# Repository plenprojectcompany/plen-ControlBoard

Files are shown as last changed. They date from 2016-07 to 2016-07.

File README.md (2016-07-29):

PLEN2 ControlBoard | PLEN Project Company
===============================================================================

## Copyright (c) 2015,
- [Naohiro HAYAISHI](http://earlystone.com/)
- [Mitsuhiro MIYAGUCHI](https://github.com/mitsuhiromiyaguchi)
- [PLEN Project Company Inc.](https://plen.jp)

## Build Environment
- Windows 8.1
- Eagle 6.60

## License
This material is released under the Creative Commons BY 4.0.

**Attention!**  
The schematic diagram of Arduino Micro in schematic file is licensed by Arduino. Please see the detail on their [web-site](https://www.arduino.cc/).
The schematic diagram of Multi-ServoMotor Interface, RS485 communication port and EEPROM is released under Creative Commons Attribution 4.0 International Public License.

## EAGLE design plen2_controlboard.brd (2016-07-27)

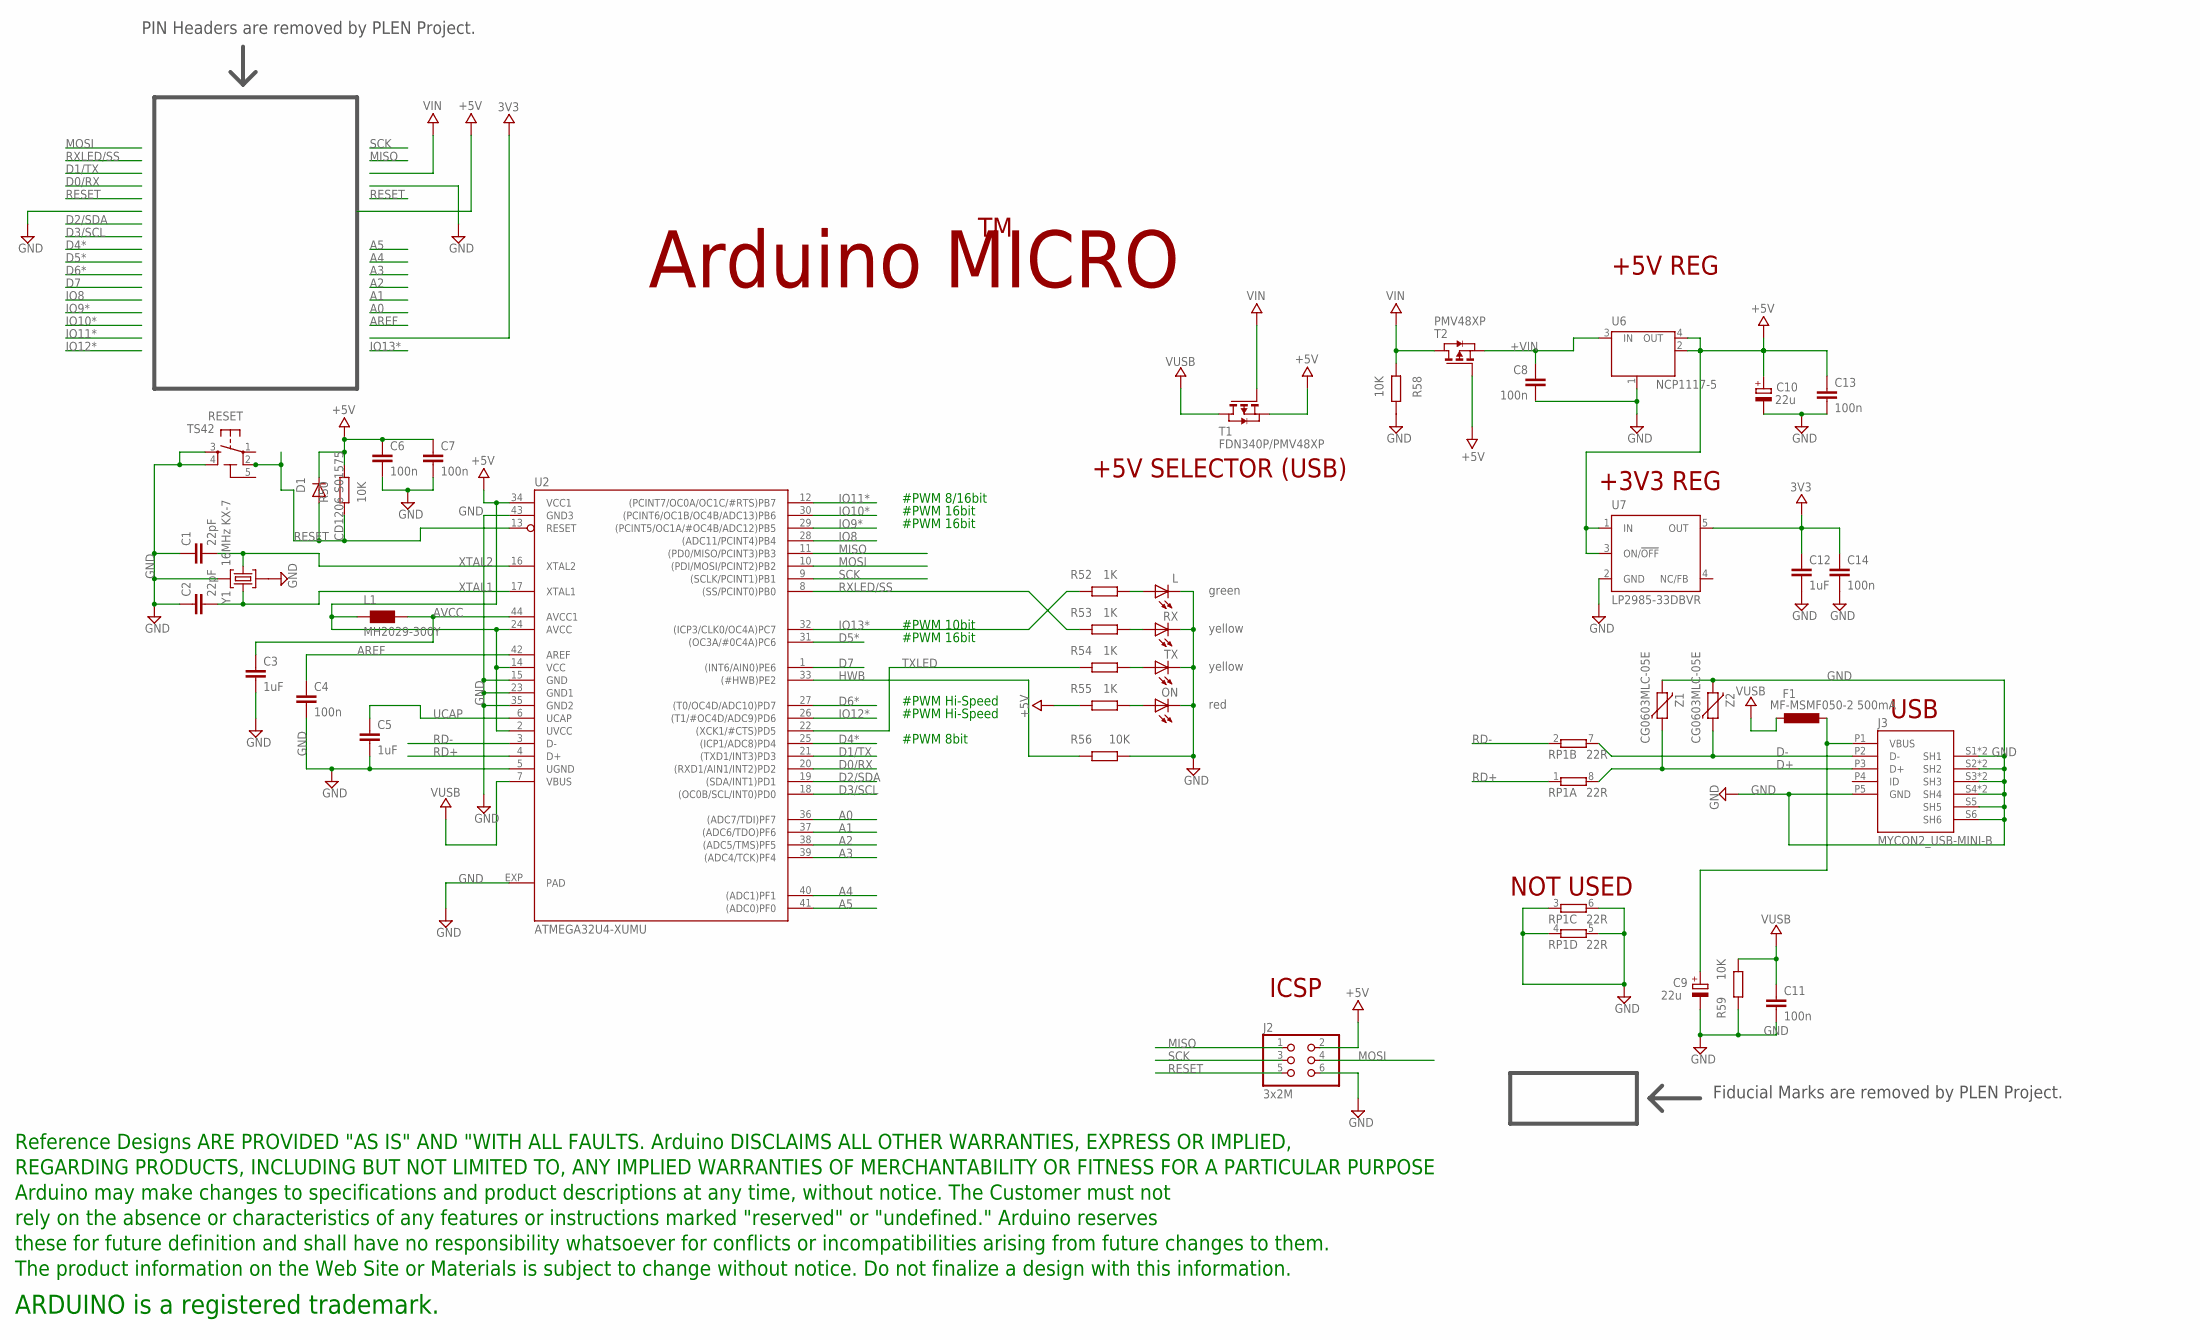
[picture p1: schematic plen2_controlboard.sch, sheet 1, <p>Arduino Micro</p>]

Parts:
C1, C2: 22pF; C0402
C3, C5, C12: 1uF; C0402
C4, C6, C7, C8, C11, C13, C14: 100n; C0402
C9, C10: 22u; SMC_B
D1: CD1206-S01575; MINIMELF
F1: MF-MSMF050-2 500mA; L1812
J2: 3x2M; 2X03
J3: MYCON2_USB-MINI-B; CON2_USB_MICRO_B_AT
L: green; CHIPLED_0805
L1: MH2029-300Y; 0805
ON: red; CHIPLED_0805
R50, R56, R58, R59: 10K; R0402
R52, R53, R54, R55: 1K; R0402
RESET: TS42
RP1: 22R; CAY16
RX: yellow; CHIPLED_0805
T1: FDN340P/PMV48XP; SOT-23
T2: PMV48XP; SOT-23
TX: yellow; CHIPLED_0805
U2: ATMEGA32U4-XUMU; QFN44ML7X7
U6: NCP1117-5; LINEAR_SOT223
U7: LP2985-33DBVR; SOT23-DBV
U$3: DISCLAIMER
Y1: 16MHz KX-7; CRYSTAL-3.2-2.5
Z1, Z2: CG0603MLC-05E; CT/CN0603

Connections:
3V3: C12.1, C14.1, U7.5 (OUT); also elsewhere on the board
5-GND: RESET.5 (5-GND)
+5V: C6.1, C7.1, C10.+, C13.1, D1.C, J2.2, L1.1, R50.1, R55.1, T1.2 (S), T2.3 (G), U2.2 (UVCC), U2.14 (VCC), U2.24 (AVCC), U2.34 (VCC1), U6.2 (OUT), U6.4 (OUT), U7.1 (IN), U7.3 (ON/!OFF); also elsewhere on the board
+VIN: C8.1, T2.2 (S), U6.3 (IN)
A0: U2.36 ((ADC7/TDI)PF7)
A1: U2.37 ((ADC6/TDO)PF6)
A2: U2.38 ((ADC5/TMS)PF5)
A3: U2.39 ((ADC4/TCK)PF4)
A4: U2.40 ((ADC1)PF1)
A5: U2.41 ((ADC0)PF0)
AREF: C4.1, U2.42 (AREF)
AVCC: C3.1, L1.2, U2.44 (AVCC1)
D0/RX: U2.20 ((RXD1/AIN1/INT2)PD2); also elsewhere on the board
D1/TX: U2.21 ((TXD1/INT3)PD3); also elsewhere on the board
D2/SDA: U2.19 ((SDA/INT1)PD1); also elsewhere on the board
D3/SCL: U2.18 ((OC0B/SCL/INT0)PD0); also elsewhere on the board
D4*: U2.25 ((ICP1/ADC8)PD4); also elsewhere on the board
D5*: U2.31 ((OC3A/#0C4A)PC6); also elsewhere on the board
D6*: U2.27 ((T0/OC4D/ADC10)PD7); also elsewhere on the board
D7: U2.1 ((INT6/AIN0)PE6)
D+: J3.P3 (D+), RP1.8 (2), Z1.1
D-: J3.P2 (D-), RP1.7 (2), Z2.1
GND: C1.1, C2.1, C3.2, C4.2, C5.2, C6.2, C7.2, C8.2, C9.-, C10.-, C11.2, C12.2, C13.2, C14.2, J2.6, J3.P5 (GND), J3.S1 (SH1), J3.S2 (SH2), J3.S3 (SH3), J3.S4 (SH4), J3.S5 (SH5), J3.S6 (SH6), J3.S7 (SH1), J3.S8 (SH2), J3.S9 (SH3), J3.S10 (SH4), L.C, ON.C, R56.2, R58.1, R59.1, RESET.3, RESET.4, RP1.3 (1), RP1.4 (1), RP1.5 (2), RP1.6 (2), RX.C, TX.C, U2.5 (UGND), U2.15 (GND), U2.23 (GND1), U2.35 (GND2), U2.43 (GND3), U2.EXP (PAD), U6.1 (GND/ADJ), U7.2 (GND), Y1.2 (GND), Y1.4 (GND), Z1.2, Z2.2; also elsewhere on the board
HWB: R56.1, U2.33 ((#HWB)PE2)
IO8: U2.28 ((ADC11/PCINT4)PB4)
IO9*: U2.29 ((PCINT5/OC1A/#OC4B/ADC12)PB5); also elsewhere on the board
IO10*: U2.30 ((PCINT6/OC1B/OC4B/ADC13)PB6); also elsewhere on the board
IO11*: U2.12 ((PCINT7/OC0A/OC1C/#RTS)PB7); also elsewhere on the board
IO12*: U2.26 ((T1/#OC4D/ADC9)PD6); also elsewhere on the board
IO13*: R52.1, U2.32 ((ICP3/CLK0/OC4A)PC7)
MISO: J2.1, U2.11 ((PD0/MISO/PCINT3)PB3)
MOSI: J2.4, U2.10 ((PDI/MOSI/PCINT2)PB2)
unnamed: R53.2, RX.A
unnamed: ON.A, R55.2
unnamed: R54.2, TX.A
unnamed: L.A, R52.2
RD+: RP1.1, U2.4 (D+)
RD-: RP1.2 (1), U2.3 (D-)
RESET: D1.A, J2.5, R50.2, RESET.2, U2.13 (RESET); also elsewhere on the board
RXLED/SS: R53.1, U2.8 ((SS/PCINT0)PB0)
SCK: J2.3, U2.9 ((SCLK/PCINT1)PB1)
TXLED: R54.1, U2.22 ((XCK1/#CTS)PD5)
UCAP: C5.1, U2.6 (UCAP)
VIN: R58.2, T1.3 (G), T2.1 (D); also elsewhere on the board
VUSB: C11.1, F1.2, R59.2, T1.1 (D), U2.7 (VBUS)
VUSBD: C9.+, F1.1, J3.P1 (VBUS)
XTAL1: C2.2, U2.17 (XTAL1), Y1.3 (C2)
XTAL2: C1.2, U2.16 (XTAL2), Y1.1 (C1)

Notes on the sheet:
Arduino MICRO
+5V REG
ICSP
USB
+5V SELECTOR (USB)
NOT USED
+3V3 REG
#PWM 8bit
#PWM Hi-Speed
#PWM 16bit
#PWM 10bit
#PWM 8/16bit
Fiducial Marks are removed by PLEN Project.
PIN Headers are removed by PLEN Project.

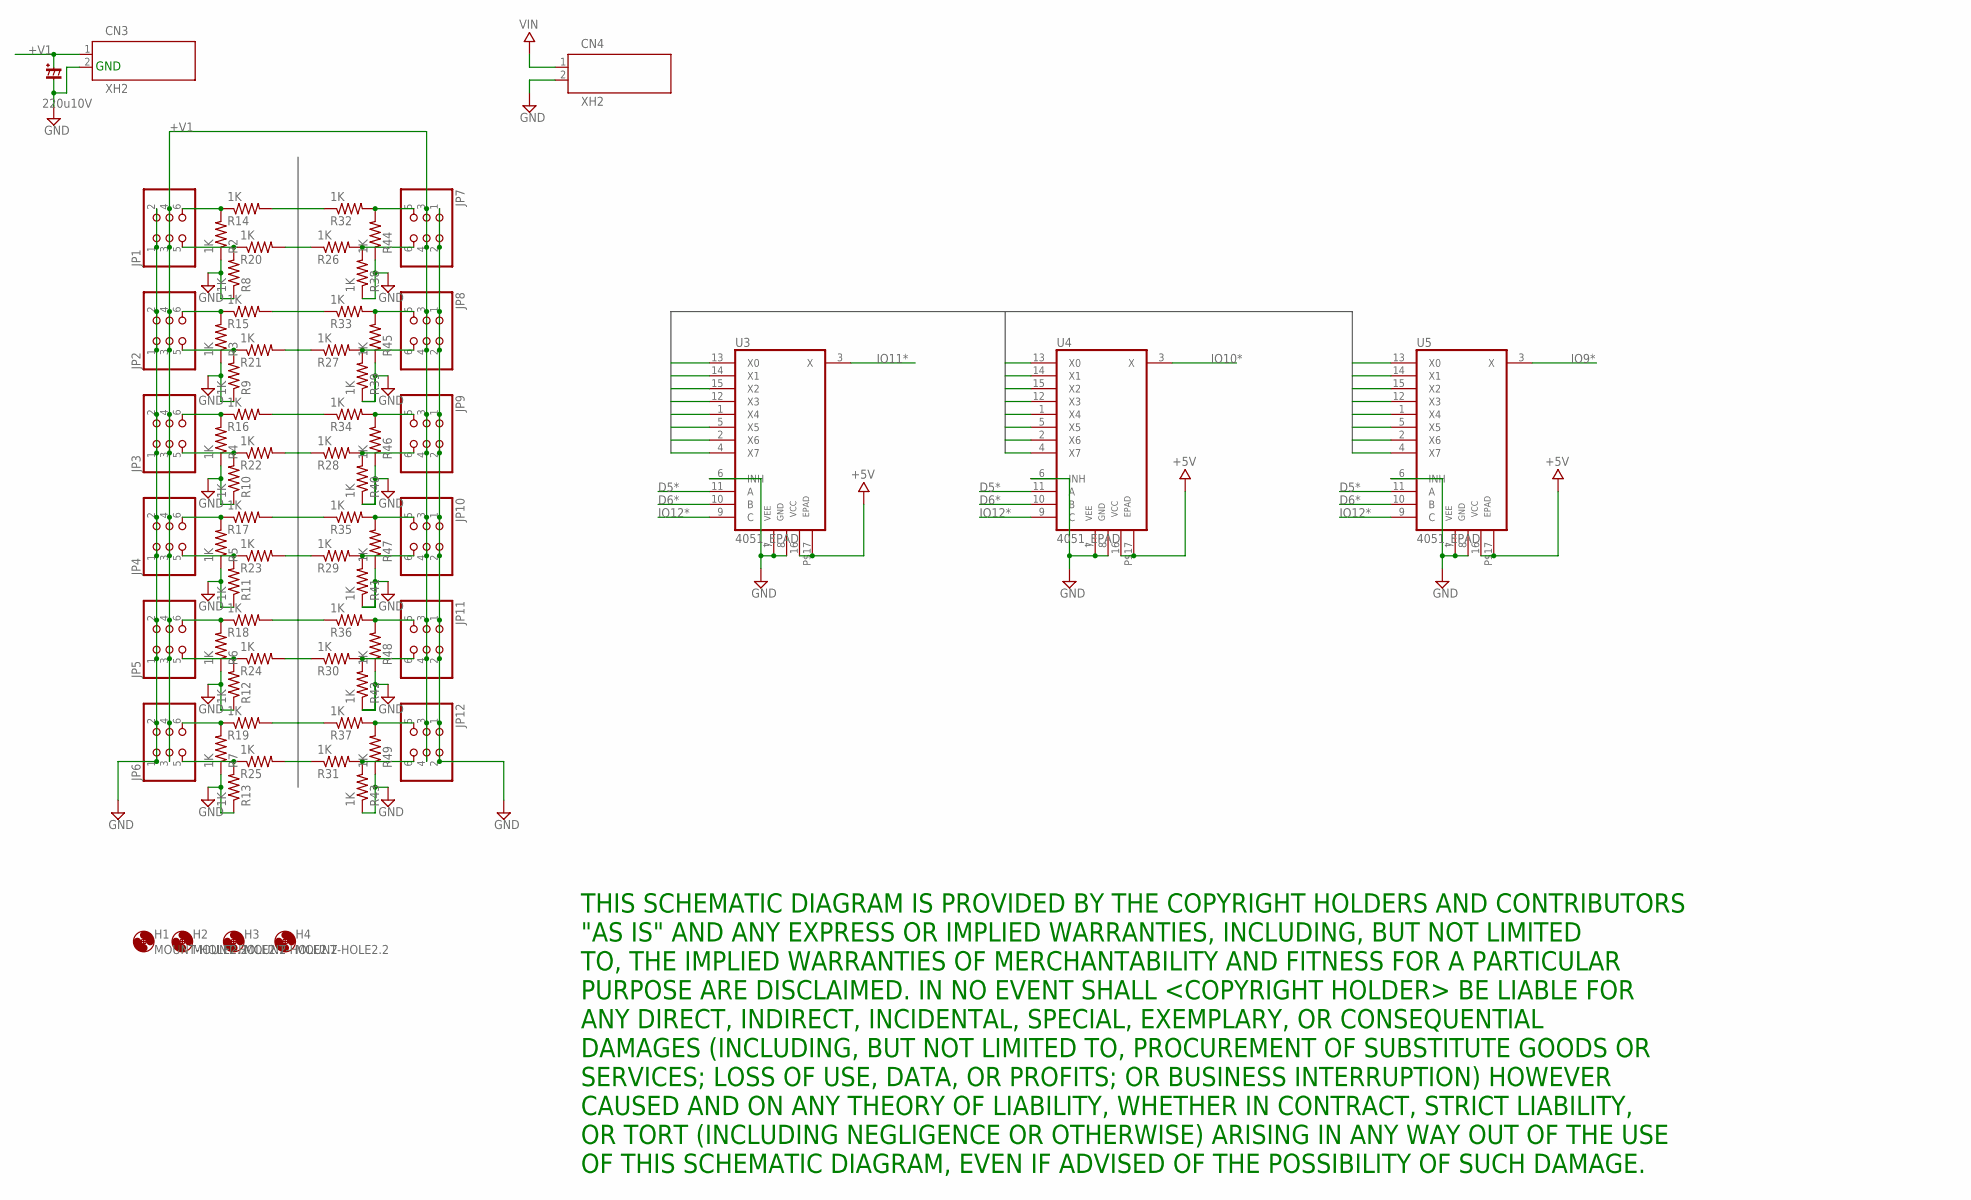
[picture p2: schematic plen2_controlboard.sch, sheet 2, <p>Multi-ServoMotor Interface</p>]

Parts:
CN3, CN4: XH2
CP1: 220u10V; CP_S05-05
H1, H2, H3, H4: MOUNT-HOLE2.2; 2,2
JP1, JP2, JP3, JP4, JP5, JP6, JP7, JP8, JP9, JP10, JP11, JP12: PINHD-2X03_2.54; 2X03
R2, R3, R4, R5, R6, R7, R8, R9, R10, R11, R12, R13, R14, R15, R16, R17, R18, R19, R20, R21, R22, R23, R24, R25, R26, R27, R28, R29, R30, R31, R32, R33, R34, R35, R36, R37, R38, R39, R40, R41, R42, R43, R44, R45, R46, R47, R48, R49: 1K; R0402S
U3, U4, U5: 4051_EPAD; SOT763-1

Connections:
+5V: U3.16 (VCC), U3.P$17 (EPAD), U4.16 (VCC), U4.P$17 (EPAD), U5.16 (VCC), U5.P$17 (EPAD); also elsewhere on the board
+V1: CN3.1, CP1.+ (1), JP1.3, JP1.4, JP2.3, JP2.4, JP3.3, JP3.4, JP4.3, JP4.4, JP5.3, JP5.4, JP6.3, JP6.4, JP7.3, JP7.4, JP8.3, JP8.4, JP9.3, JP9.4, JP10.3, JP10.4, JP11.3, JP11.4, JP12.3, JP12.4
D5*: U3.11 (A), U4.11 (A), U5.11 (A); also elsewhere on the board
D6*: U3.10 (B), U4.10 (B), U5.10 (B); also elsewhere on the board
GND: CN3.2, CN4.2, CP1.- (2), JP1.1, JP1.2, JP2.1, JP2.2, JP3.1, JP3.2, JP4.1, JP4.2, JP5.1, JP5.2, JP6.1, JP6.2, JP7.1, JP7.2, JP8.1, JP8.2, JP9.1, JP9.2, JP10.1, JP10.2, JP11.1, JP11.2, JP12.1, JP12.2, R2.1, R3.1, R4.1, R5.1, R6.1, R7.1, R8.1, R9.1, R10.1, R11.1, R12.1, R13.1, R38.1, R39.1, R40.1, R41.1, R42.1, R43.1, R44.1, R45.1, R46.1, R47.1, R48.1, R49.1, U3.6 (INH), U3.7 (VEE), U3.8 (GND), U4.6 (INH), U4.7 (VEE), U4.8 (GND), U5.6 (INH), U5.7 (VEE), U5.8 (GND); also elsewhere on the board
IO9*: U5.3 (X); also elsewhere on the board
IO10*: U4.3 (X); also elsewhere on the board
IO11*: U3.3 (X); also elsewhere on the board
IO12*: U3.9 (C), U4.9 (C), U5.9 (C); also elsewhere on the board
unnamed: JP1.5, R8.2, R20.1
unnamed: JP1.6, R2.2, R14.1
unnamed: JP3.5, R10.2, R22.1
unnamed: JP2.5, R9.2, R21.1
unnamed: JP2.6, R3.2, R15.1
unnamed: JP3.6, R4.2, R16.1
unnamed: JP4.5, R11.2, R23.1
unnamed: JP4.6, R5.2, R17.1
unnamed: JP5.5, R12.2, R24.1
unnamed: JP5.6, R6.2, R18.1
unnamed: JP6.5, R13.2, R25.1
unnamed: JP6.6, R7.2, R19.1
unnamed: JP7.5, R32.2, R44.2
unnamed: JP7.6, R26.2, R38.2
unnamed: JP9.5, R34.2, R46.2
unnamed: JP8.5, R33.2, R45.2
unnamed: JP8.6, R27.2, R39.2
unnamed: JP9.6, R28.2, R40.2
unnamed: JP10.5, R35.2, R47.2
unnamed: JP10.6, R29.2, R41.2
unnamed: JP11.5, R36.2, R48.2
unnamed: JP11.6, R30.2, R42.2
unnamed: JP12.5, R37.2, R49.2
unnamed: JP12.6, R31.2, R43.2
SRV0: R14.2, U3.13 (X0)
SRV1: R20.2, U3.14 (X1)
SRV2: R15.2, U3.15 (X2)
SRV3: R21.2, U3.12 (X3)
SRV4: R16.2, U3.1 (X4)
SRV5: R22.2, U3.5 (X5)
SRV6: R17.2, U3.2 (X6)
SRV7: R23.2, U3.4 (X7)
SRV8: R18.2, U4.13 (X0)
SRV9: R24.2, U4.14 (X1)
SRV10: R19.2, U4.15 (X2)
SRV11: R25.2, U4.12 (X3)
SRV12: R32.1, U4.1 (X4)
SRV13: R26.1, U4.5 (X5)
SRV14: R33.1, U4.2 (X6)
SRV15: R27.1, U4.4 (X7)
SRV16: R34.1, U5.13 (X0)
SRV17: R28.1, U5.14 (X1)
SRV18: R35.1, U5.15 (X2)
SRV19: R29.1, U5.12 (X3)
SRV20: R36.1, U5.1 (X4)
SRV21: R30.1, U5.5 (X5)
SRV22: R37.1, U5.2 (X6)
SRV23: R31.1, U5.4 (X7)
VIN: CN4.1; also elsewhere on the board

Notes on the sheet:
GND
THIS SCHEMATIC DIAGRAM IS PROVIDED BY THE COPYRIGHT HOLDERS AND CONTRIBUTORS "AS IS" AND ANY EXPRESS OR IMPLIED WARRANTIES, INCLUDING, BUT NOT LIMITED TO, THE IMPLIED WARRANTIES OF MERCHANTABILITY AND FITNESS FOR A PARTICULAR PURPOSE ARE DISCLAIMED. IN NO EVENT SHALL <COPYRIGHT HOLDER> BE LIABLE FO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

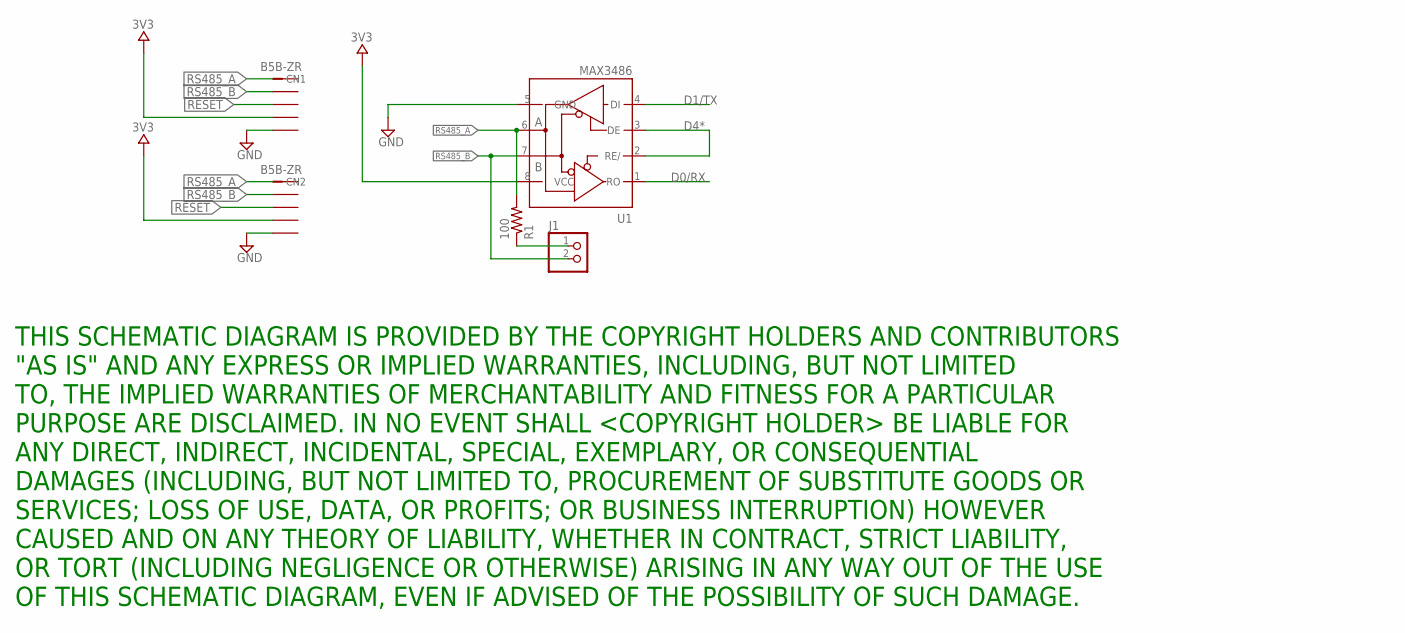
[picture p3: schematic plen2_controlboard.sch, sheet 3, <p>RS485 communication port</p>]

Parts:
CN1, CN2: B5B-ZR
J1: PINHD-1X2; 1X02
R1: 100; R0402S
U1: MAX3486; SO08

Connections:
3V3: CN1.4, CN2.4, U1.8 (VCC); also elsewhere on the board
D0/RX: U1.1 (RO); also elsewhere on the board
D1/TX: U1.4 (DI); also elsewhere on the board
D4*: U1.2 (RE/), U1.3 (DE); also elsewhere on the board
GND: CN1.5, CN2.5, U1.5 (GND); also elsewhere on the board
unnamed: J1.1, R1.1
RESET: CN1.3, CN2.3; also elsewhere on the board
RS485_A: CN1.1, CN2.1, R1.2, U1.6 (A)
RS485_B: CN1.2, CN2.2, J1.2, U1.7 (B)

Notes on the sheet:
THIS SCHEMATIC DIAGRAM IS PROVIDED BY THE COPYRIGHT HOLDERS AND CONTRIBUTORS "AS IS" AND ANY EXPRESS OR IMPLIED WARRANTIES, INCLUDING, BUT NOT LIMITED TO, THE IMPLIED WARRANTIES OF MERCHANTABILITY AND FITNESS FOR A PARTICULAR PURPOSE ARE DISCLAIMED. IN NO EVENT SHALL <COPYRIGHT HOLDER> BE LIABLE FO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

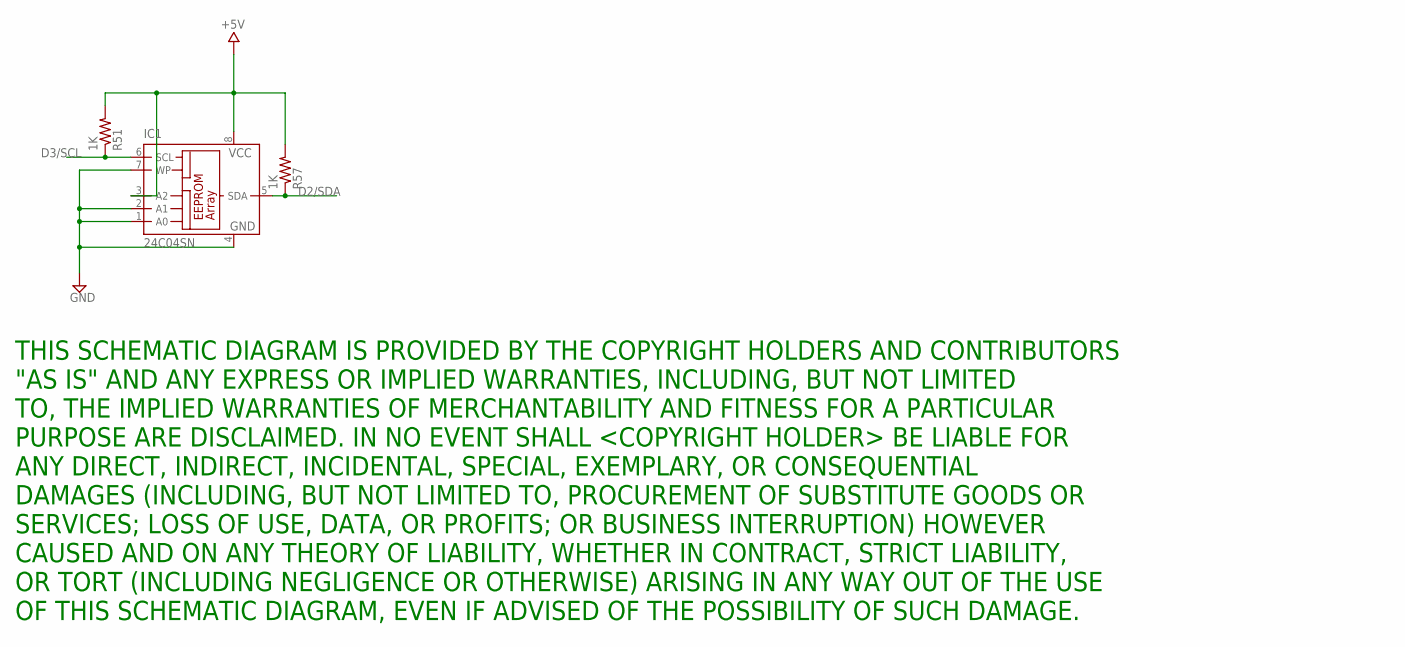
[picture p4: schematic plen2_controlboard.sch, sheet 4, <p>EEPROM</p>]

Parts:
IC1: 24C04SN; SO-08
R51, R57: 1K; R0402S

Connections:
+5V: IC1.3 (A2), IC1.8 (VCC), R51.2, R57.2; also elsewhere on the board
D2/SDA: IC1.5 (SDA), R57.1; also elsewhere on the board
D3/SCL: IC1.6 (SCL), R51.1; also elsewhere on the board
GND: IC1.1 (A0), IC1.2 (A1), IC1.4 (GND), IC1.7 (WP); also elsewhere on the board

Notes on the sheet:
THIS SCHEMATIC DIAGRAM IS PROVIDED BY THE COPYRIGHT HOLDERS AND CONTRIBUTORS "AS IS" AND ANY EXPRESS OR IMPLIED WARRANTIES, INCLUDING, BUT NOT LIMITED TO, THE IMPLIED WARRANTIES OF MERCHANTABILITY AND FITNESS FOR A PARTICULAR PURPOSE ARE DISCLAIMED. IN NO EVENT SHALL <COPYRIGHT HOLDER> BE LIABLE FO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

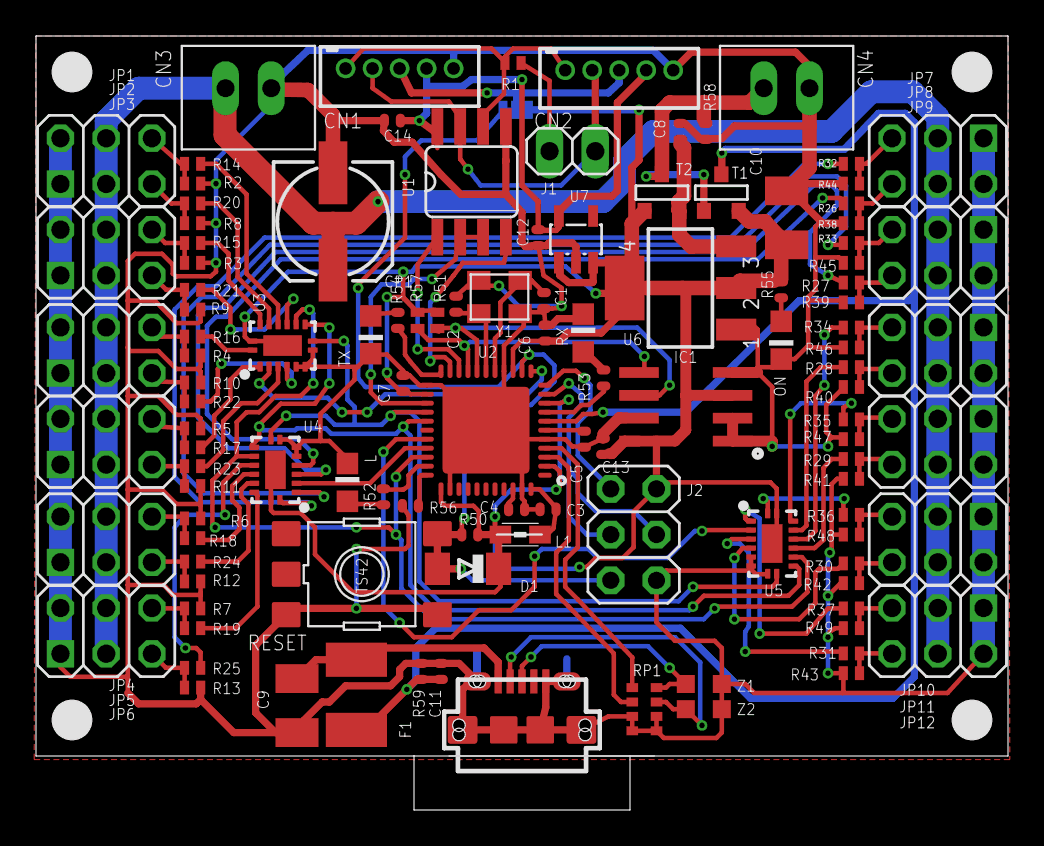
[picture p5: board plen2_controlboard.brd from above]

Board: 2 copper layers, 54.0 x 43.0 mm, 120 parts (0 on the bottom side), 91 nets.

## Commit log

2015-08-31 Added eagle files.
    [plen_baseboard.brd, plen_baseboard.sch]
2016-03-21 Fix file-names & documents
    [plen2_controlboard.brd, plen2_controlboard.sch]
2016-07-27 Fix power line
    [plen2_controlboard.brd]
